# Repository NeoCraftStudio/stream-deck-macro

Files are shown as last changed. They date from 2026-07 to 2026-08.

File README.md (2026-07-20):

# Stream Deck Macro

DIY macro deck (Elgato Stream Deck style), built around an Arduino Pro Micro
(ATmega32U4): 4x4 button matrix with a secondary layer (2FX), 3 rotary
encoders for audio control, and individually addressable WS2812B LEDs per
key.

A companion Python app (PySide6) receives firmware events over serial and
executes the configured actions: keyboard shortcuts, OBS scene control, sound
playback, and real per-app mute.

## Status

In active development. Firmware phases (matrix, encoder, LEDs) verified on
hardware; app-side phases (serial reader, config, keyboard/audio/OBS
actions, 2FX logic) verified individually. Full roadmap below.

## Roadmap

```mermaid
flowchart TD
    S["Setup: Git + GitHub + Docs"]:::done --> P0["Phase 0: Hardware check"]:::done
    P0 --> P1["Phase 1: Firmware bring-up"]:::done
    P1 --> P2["Phase 2: Button matrix"]:::done
    P2 --> P3["Phase 3: Encoders"]:::done
    P3 --> P4["Phase 4: WS2812B LEDs"]:::done
    P4 --> P5["Phase 5: Merge + two-way protocol"]:::done
    P5 --> P6["Phase 6: App serial reader"]:::done
    P6 --> P7["Phase 7: Config format"]:::done
    P7 --> P8["Phase 8: Keyboard shortcuts"]:::done
    P8 --> P9["Phase 9: Audio playback"]:::done
    P9 --> P10["Phase 10: OBS control"]:::done
    P10 --> P11["Phase 11: Per-process mute"]:::done
    P11 --> P12["Phase 12: 2FX state machine"]:::done
    P12 --> P13["Phase 13: GUI (PySide6)"]:::done
    P13 --> P14["Phase 14: Full integration"]:::done
    P14 --> P15["Phase 15: Packaging .exe"]:::current
    P0 -.-> C["Case: 3D-printed enclosure"]:::todo
    C -.-> P14

    classDef done fill:#2ea043,stroke:#2ea043,color:#fff
    classDef current fill:#d29922,stroke:#d29922,color:#000
    classDef todo fill:#30363d,stroke:#8b949e,color:#c9d1d9
```

Full checklist with descriptions: [ROADMAP.md](ROADMAP.md)

## Learning project

This repository is also a learning exercise in Git, GitHub, and Python.

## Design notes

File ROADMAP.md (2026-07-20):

# Roadmap

Each phase is a prerequisite for the next one, unless marked as a parallel
track. Status is updated manually as the project progresses.

> **🟢 Resolved (2026-07-19): the Pro Micro's USB enumeration failure was a
> reset-timing issue (double-tap RST/GND needs to happen mid-upload, not
> before), not a hardware fault — same board recovered, no replacement
> needed. Details in `CLAUDE.md`.**

```mermaid
flowchart TD
    S["Setup: Git + GitHub + Docs"]:::done --> P0["Phase 0: Hardware check"]:::done
    P0 --> P1["Phase 1: Firmware bring-up"]:::done
    P1 --> P2["Phase 2: Button matrix"]:::done
    P2 --> P3["Phase 3: Encoders"]:::done
    P3 --> P4["Phase 4: WS2812B LEDs"]:::done
    P4 --> P5["Phase 5: Merge + two-way protocol"]:::done
    P5 --> P6["Phase 6: App serial reader"]:::done
    P6 --> P7["Phase 7: Config format"]:::done
    P7 --> P8["Phase 8: Keyboard shortcuts"]:::done
    P8 --> P9["Phase 9: Audio playback"]:::done
    P9 --> P10["Phase 10: OBS control"]:::done
    P10 --> P11["Phase 11: Per-process mute"]:::done
    P11 --> P12["Phase 12: 2FX state machine"]:::done
    P12 --> P13["Phase 13: GUI (PySide6)"]:::done
    P13 --> P14["Phase 14: Full integration"]:::done
    P14 --> P15["Phase 15: Packaging .exe"]:::current
    P0 -.-> C["Case: 3D-printed enclosure"]:::todo
    C -.-> P14

    classDef done fill:#2ea043,stroke:#2ea043,color:#fff
    classDef current fill:#d29922,stroke:#d29922,color:#000
    classDef todo fill:#30363d,stroke:#8b949e,color:#c9d1d9
```

🟢 done · 🟡 current · ⬛ not started

## Checklist

- [x] Setup — Git, GitHub repo, README, LICENSE, .gitignore, CLAUDE.md
- [x] Phase 0 — Hardware check (confirmed: Pro Micro 5V / 16MHz variant, no level shifter needed)
- [x] Phase 1 — Firmware bring-up (toolchain, blink, serial hello world)
- [x] Phase 2 — Firmware: button matrix scanning (all 16 positions confirmed)
- [x] Phase 3 — Firmware: rotary encoders (CW/CCW/PUSH logic verified on 1 of 3 encoders; other 2 are only repeats of the same wiring, to be confirmed when in hand)
- [x] Phase 4 — Firmware: WS2812B LEDs (chaining + color order confirmed on 9 spare bare LEDs; original 100+ LED reel is faulty, unresolved — see CLAUDE.md)
- [x] Phase 5 — Firmware: merge (matrix + encoder + LEDs, one sketch) done; **two-way protocol (PC→firmware LED commands) deliberately deferred** — revisit before Phase 14
- [x] Phase 6 — App: serial reader (pyserial), confirmed reading BTN/ENC events live
- [x] Phase 7 — App: config file format (JSON schema designed, `config.json` sample + loader confirmed working)
- [x] Phase 8 — App: keyboard shortcut execution (`pyautogui`, confirmed via config-driven `ctrl+c` test)
- [x] Phase 9 — App: audio playback (`sounddevice`, confirmed routing through VB-Cable to a specific device)
- [x] Phase 10 — App: OBS control (`obsws-python`, confirmed scene switch)
- [x] Phase 11 — App: real per-process mute (`pycaw`, mute + unmute both confirmed on `opera.exe`)
- [x] Phase 12 — App: 2FX layer state machine (arm/cancel/timeout/layer-2-fire all confirmed against real hardware)
- [x] Phase 13 — App: GUI (PySide6) — grid, per-key config popup (incl. recorded-macro type), 2FX timeout settings, and per-encoder config (system vs. per-app via file picker) all confirmed saving to config.json
- [x] Phase 14 — Full integration: firmware two-way command (`LED:SOLID:r,g,b`) confirmed, app listens to serial live via a `QTimer` (non-blocking, GUI stays responsive) and executes real actions (keyboard/macro, sound, OBS scene) through the 2FX logic. Follow-up polish (not blocking): app doesn't yet send LED feedback on 2FX arm/disarm, encoder events not yet wired to volume/mute.
- [ ] Phase 15 — Packaging (PyInstaller .exe) **← current**
- [ ] Case — 3D-printed enclosure (parallel track, not blocking)

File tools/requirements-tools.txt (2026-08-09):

# Build-time-only tools — NOT runtime dependencies of app.py.
# Install into .venv only when regenerating the icon or the manual PDF:
#   pip install -r tools/requirements-tools.txt
pillow
markdown
pymupdf
pyinstaller

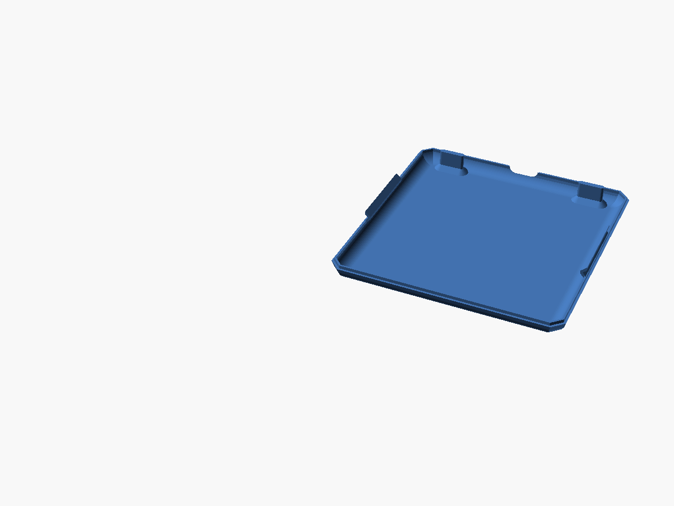
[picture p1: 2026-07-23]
case/renders/ocreeb_bottom_original.png

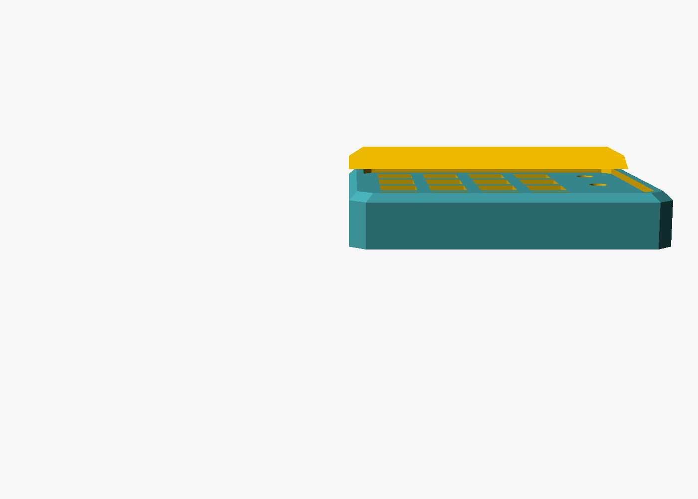
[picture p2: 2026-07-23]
case/renders/case_v5_riser_side.png

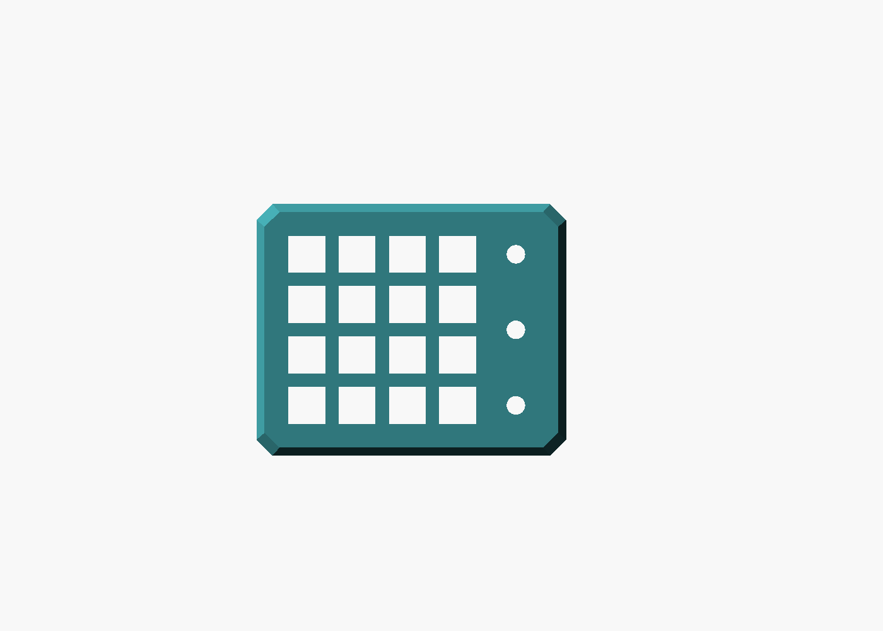
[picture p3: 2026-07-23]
case/renders/case_v4_top_view.png

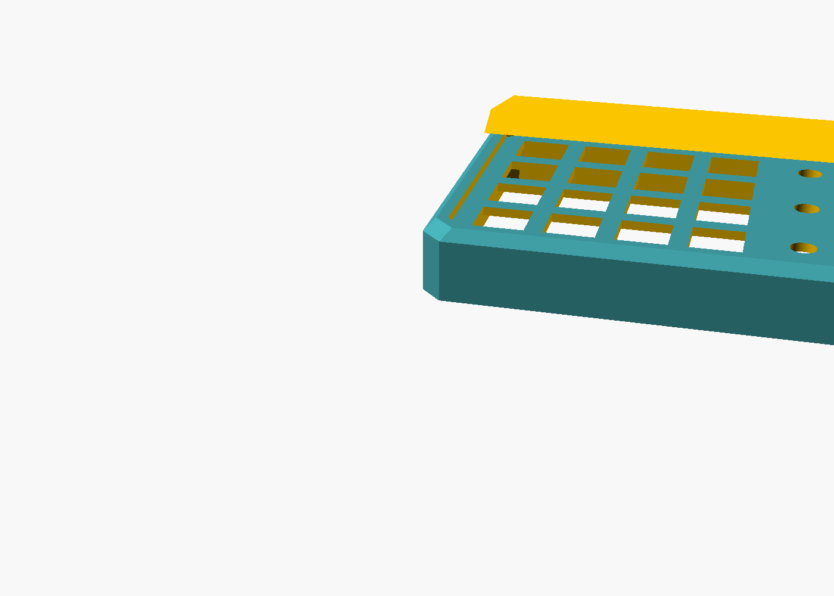
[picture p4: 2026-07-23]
case/renders/case_v5_check.png

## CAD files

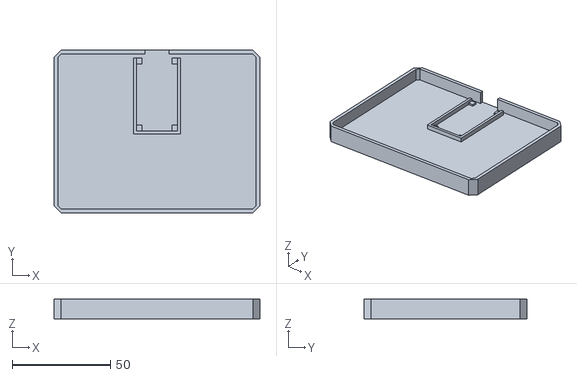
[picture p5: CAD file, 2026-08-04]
case/case_bottom.stl
104.7 x 82.7 x 10.0

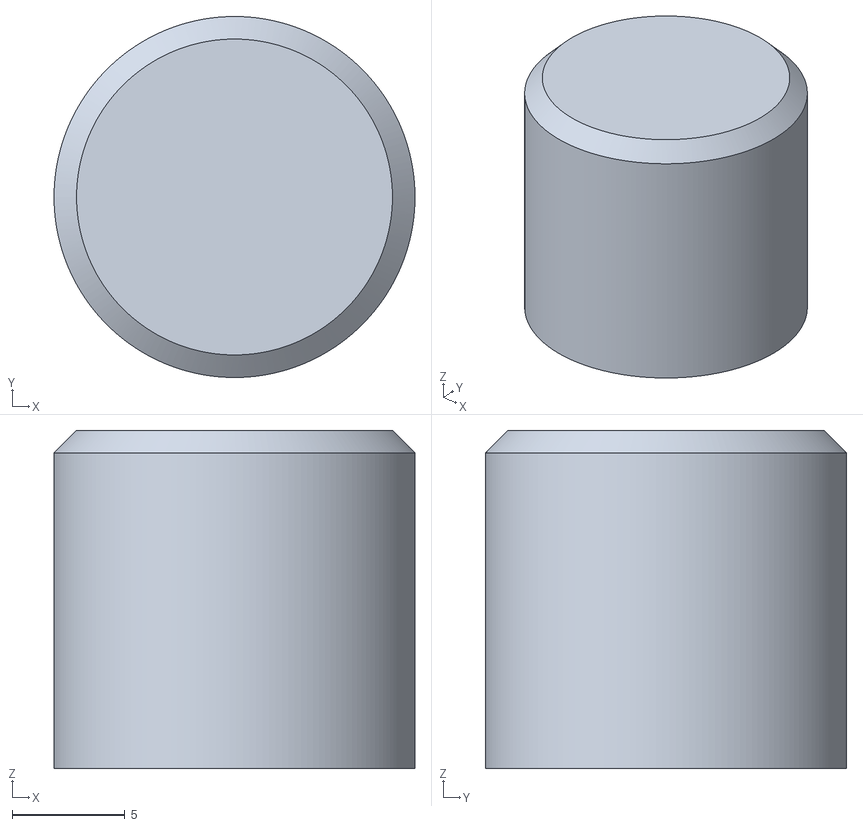
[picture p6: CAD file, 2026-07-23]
case/reference/Knob.stl
16.0 x 16.0 x 15.0

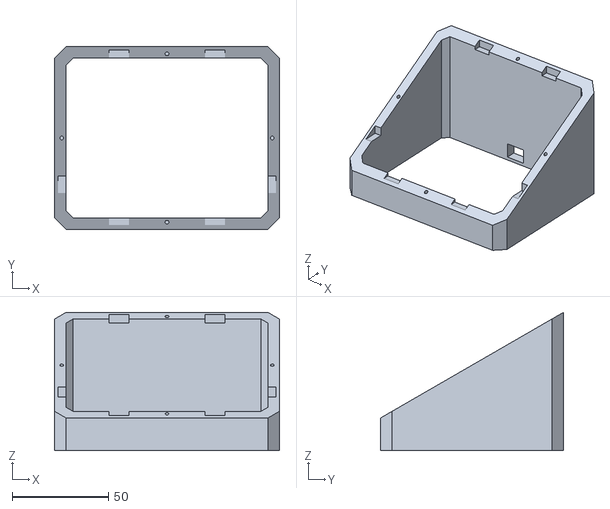
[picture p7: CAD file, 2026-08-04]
case/case_mount.stl
117.2 x 95.2 x 71.9

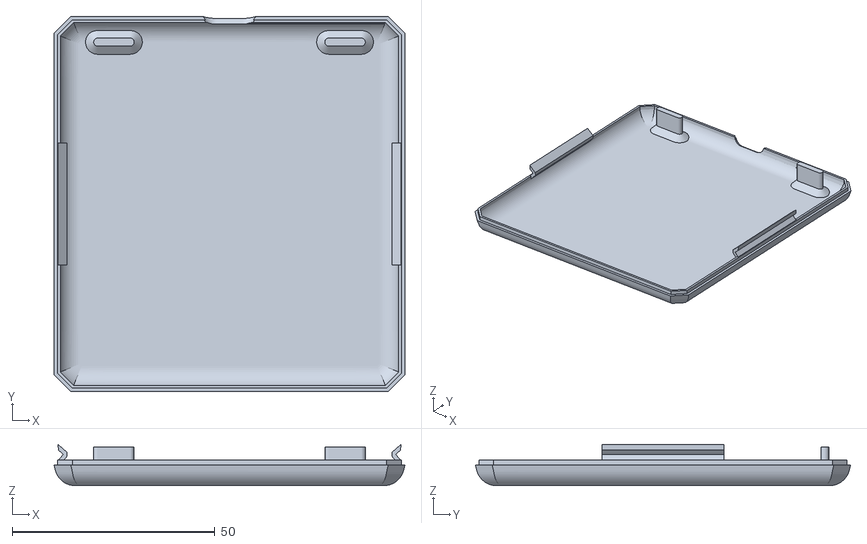
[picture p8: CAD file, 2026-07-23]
case/reference/Case_Bottom.stl
86.6 x 92.5 x 10.2

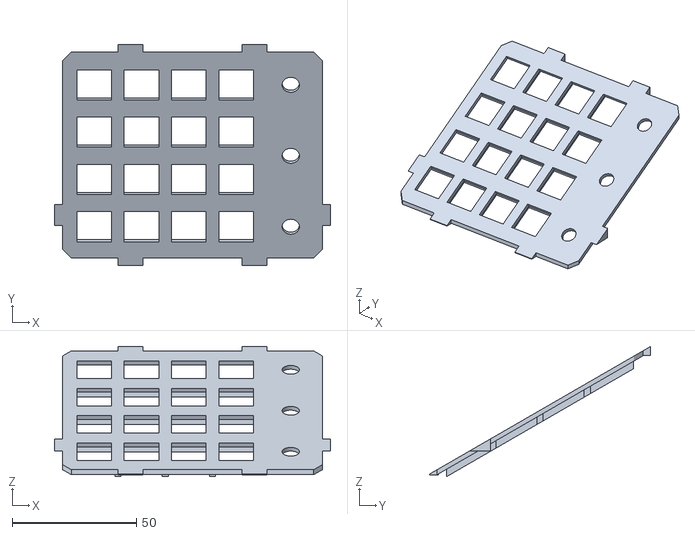
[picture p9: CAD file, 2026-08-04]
case/case_deck.stl
111.2 x 89.2 x 52.4

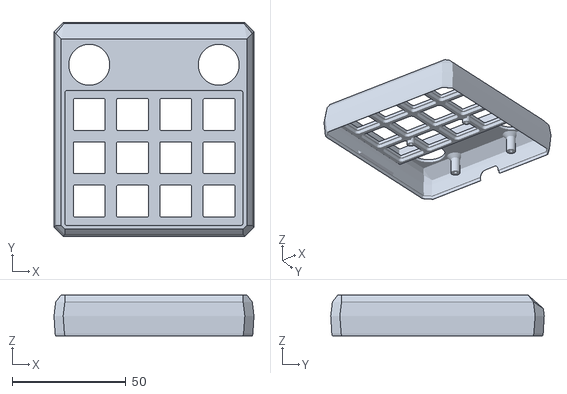
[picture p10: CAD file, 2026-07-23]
case/reference/Case_Top.stl
88.0 x 94.0 x 18.0

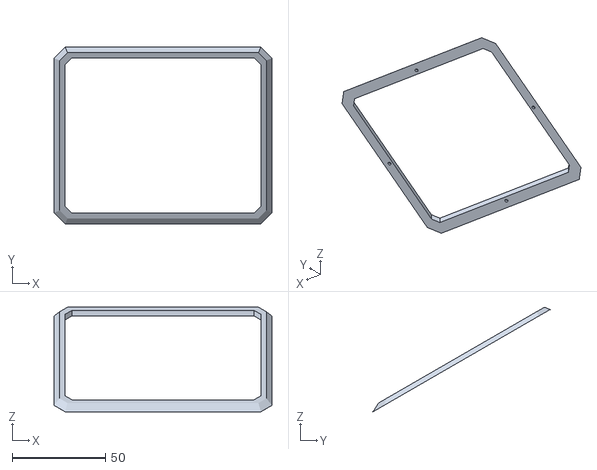
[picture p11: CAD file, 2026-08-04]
case/case_crest.stl
117.2 x 95.2 x 56.2

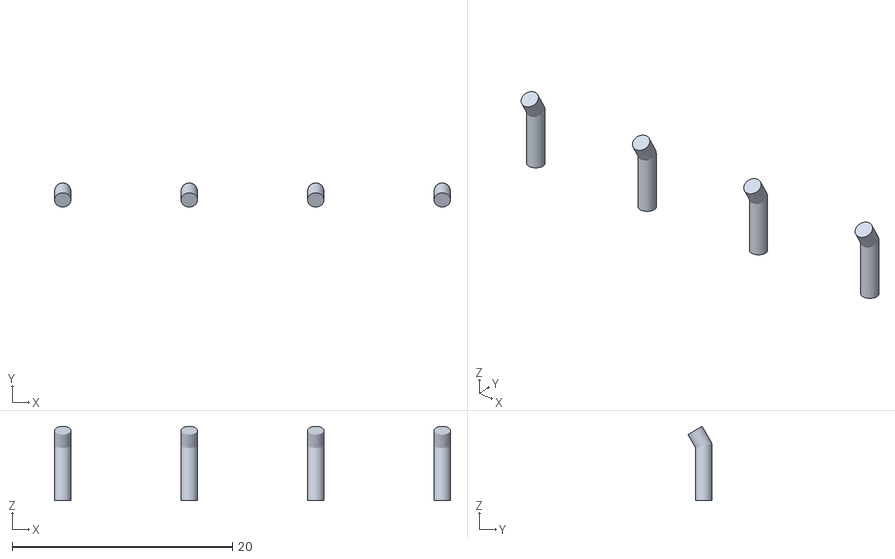
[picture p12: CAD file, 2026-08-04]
case/case_pins.stl
36.0 x 2.20 x 6.76

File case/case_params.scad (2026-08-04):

// Stream Deck Macro — shared case dimensions (included by top/bottom/assembly)

// ---- Our target layout ----
switch_hole   = 14;
switch_pitch  = 19.05;
grid_cols     = 4;
grid_rows     = 4;
grid_span     = (grid_cols - 1) * switch_pitch + switch_hole; // 71.15

encoder_d     = 7;       // CONFIRMED two ways: caliper-measured on the actual purchased part,
                          // and matches the encoder's own spec — Keszoox's EC11 datasheet states
                          // "Panel Mount — M7 thread fits standard 7mm panel holes with included
                          // nut" for this exact family (EC11, 15mm shaft, half/D-shaft — matches
                          // the purchased "G 15mm Half handle" spec). No longer a placeholder.
encoder_count = 3;
encoder_gap   = 15;

margin = 12;

// ---- Shell style ----
corner_chamfer = 6;    // diagonal cut on each of the 4 corners
rim_height     = 20;   // total wall height (top to bottom), 2cm per feedback
bevel_height   = 3;    // top tapered collar height
bevel_inset    = 3;    // how far the top face is inset from the outer wall
border         = 6;    // rim wall thickness (outer edge to inner hollow)
deck_recess    = 2.5;  // how far below the rim top the switch deck sits
deck_thickness = 2.5;  // thickness of the switch deck floor

// switch_hole (14mm) and switch_pitch (19.05mm) are the universal Cherry
// MX-compatible plate-mount standard — every mechanical switch
// manufacturer uses this same spacing, Outemu (the purchased switch,
// "Dustproof Brown") included. Not brand-specific, so there's nothing to
// confirm against the specific part the way encoder_d needed — this was
// already correct.

plate_w = margin*2 + grid_span + encoder_gap + encoder_d;
plate_d = margin*2 + grid_span;

// ---- Arduino Pro Micro mount (off-the-shelf part) ----
// CONFIRMED (AliExpress order, seller A+A+A Store): "MICRO/MINI/TYPE-C USB
// Pro Micro para arduino ATmega32U4", ordered as TYPE-C USB 5V/16MHz — NOT
// Micro-USB, correcting an earlier assumption this file was built around.
// Board size still web-sourced, not caliper-measured: multiple listings
// (Probots, Envistia Mall, Makers Electronics) cite ~33x18mm for this
// family; Keebio notes the USB-C variant specifically runs ~3mm longer
// than the Micro-USB version (~36mm) because of the connector footprint.
// arduino_l=38 already covers that with ~2mm to spare. Confirm with
// calipers before printing final — same convention as encoder_d.
//
// USB-C connector: standard panel-mount cutout per connector datasheets is
// 12mm x 8.4mm (the bare plug shell is ~8.4mm wide x 2.6-2.9mm tall, but
// the cable's outer sleeve needs the fuller cutout to actually pass
// through). usb_cutout_w/h below (12x9) already satisfy that with a
// little extra margin on height — no change needed now that the
// connector type is confirmed, this is just the correct citation for why
// those numbers work, replacing the old Micro-USB-based reasoning.
arduino_l          = 37;   // pocket length (Y) — tightened from a generic 38mm margin. Better
                            // data now: base Pro Micro is ~33mm, and Keebio (who sells the exact
                            // USB-C variant) states it specifically runs ~3mm longer than the
                            // Micro-USB version because of the connector footprint = ~36mm for
                            // this board. 37mm leaves 1mm clearance, tighter than before because
                            // this number is better-reasoned now, not because the underlying
                            // uncertainty (calipers not yet done) has changed.
arduino_w          = 21;   // pocket width (X) — board's ~18-18.4mm wide edge + margin. Width
                            // doesn't vary between Micro-USB/USB-C variants (only length does,
                            // from the connector), so no equivalent tightening applies here.
arduino_wall_t     = 1.5;  // retaining wall thickness (bottom tray)
arduino_wall_h     = 2.5;  // retaining wall height — keeps the board from sliding sideways
arduino_standoff_h = 1;    // corner standoff height — lifts the board off the floor slightly,
                            // clearing any solder blobs on the underside

usb_cutout_w  = 12;  // wall cutout width — matches the standard USB-C panel cutout width
usb_cutout_h  = 9;   // wall cutout height — standard USB-C panel cutout is 8.4mm; 9mm keeps
                      // a small margin above that
usb_cutout_z0 = 2;   // wall cutout bottom, world Z — still an ESTIMATE (~5.5mm port center
                      // above the tray floor), not measured against the actual board's port
                      // height. This is unrelated to the Micro-USB/USB-C question and still
                      // needs a test-fit or caliper check before printing final.

// Board centered in X, pushed to the BACK (max Y) of the case, USB port
// facing the back wall so the cable exits there — position shared between
// case_v4_bottom.scad (the pocket) and case_v4_top.scad (the wall cutout)
// so they're guaranteed to align, rather than two separately-guessed numbers.
arduino_x_center = plate_w / 2;
arduino_y_back   = plate_d - border - 4.25; // The tray's own inner cavity back boundary sits at
                            // plate_d - border - fit_clearance(0.25) - wall_thickness(2) = 86.9,
                            // not plate_d - border(89.15) — those extra two values belong to
                            // case_v4_bottom.scad specifically. Using -4.25 here (2mm safety
                            // margin past that real boundary) keeps the pocket safely inside the
                            // tray's actual cavity instead of overlapping its own back wall.

module chamfered_rect(w, d, c) {
    polygon(points = [
        [c, 0], [w - c, 0],
        [w, c], [w, d - c],
        [w - c, d], [c, d],
        [0, d - c], [0, c]
    ]);
}

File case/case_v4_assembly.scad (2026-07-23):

// Fit-check only — both pieces as plain solid geometry.

include <case_params.scad>
use <case_v4_top.scad>
use <case_v4_bottom.scad>

case_top();
case_bottom();

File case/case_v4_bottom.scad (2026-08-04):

// Stream Deck Macro — bottom plate v4 (tray with sliding wall)
// Slides up into the top piece's inner cavity from below. The tray's outer
// wall matches the top's inner hollow, minus a small per-side clearance so
// it can actually slide in once printed.

include <case_params.scad>

fit_clearance    = 0.25; // per-side gap for a sliding fit
floor_thickness  = 3;    // tray floor thickness
wall_thickness   = 2;    // tray's own perimeter wall thickness
wall_height      = 10;   // how tall the tray wall is (slides into the top's cavity)

bottom_w = (plate_w - 2*border) - 2*fit_clearance;
bottom_d = (plate_d - 2*border) - 2*fit_clearance;
bottom_chamfer = corner_chamfer * 0.6;

module arduino_mount() {
    // 3-sided retaining wall — left, right, and the far (low-Y) side —
    // left OPEN on the back (high-Y) side facing the USB cutout, so
    // there's nothing blocking cable clearance or sliding the board in
    // from that direction. Corner standoffs lift the board slightly off
    // the floor.
    z0 = floor_thickness;
    x0 = arduino_x_center - arduino_w/2;
    y0 = arduino_y_back - arduino_l;
    translate([x0 - arduino_wall_t, y0, z0])
        cube([arduino_wall_t, arduino_l, arduino_wall_h]);
    translate([x0 + arduino_w, y0, z0])
        cube([arduino_wall_t, arduino_l, arduino_wall_h]);
    translate([x0 - arduino_wall_t, y0 - arduino_wall_t, z0])
        cube([arduino_w + 2*arduino_wall_t, arduino_wall_t, arduino_wall_h]);
    standoff_size = 3;
    for (dx = [0, arduino_w - standoff_size])
        for (dy = [0, arduino_l - standoff_size])
            translate([x0 + dx, y0 + dy, z0])
                cube([standoff_size, standoff_size, arduino_standoff_h]);
}

module case_bottom() {
    translate([border + fit_clearance, border + fit_clearance, 0])
        difference() {
            linear_extrude(height = wall_height)
                chamfered_rect(bottom_w, bottom_d, bottom_chamfer);
            translate([wall_thickness, wall_thickness, floor_thickness])
                linear_extrude(height = wall_height)
                    chamfered_rect(bottom_w - 2*wall_thickness,
                                   bottom_d - 2*wall_thickness,
                                   max(bottom_chamfer - wall_thickness, 0.1));
            // USB cable notch through the TRAY'S OWN back wall — without
            // this, the wall added a few lines above (wall_thickness
            // thick) sits directly between the Arduino pocket and the
            // matching cutout in the mount's back wall, blocking the
            // cable path entirely. Reported directly: "the hole for the
            // cable is blocked for the back wall of the bottom."
            // bottom_w/2 in this LOCAL frame is exactly arduino_x_center
            // in world coordinates (border+fit_clearance cancels out),
            // so this lines up with the mount's cutout without needing
            // to duplicate that math.
            translate([bottom_w/2 - usb_cutout_w/2, bottom_d - wall_thickness - 1, floor_thickness])
                cube([usb_cutout_w, wall_thickness + 2, wall_height - floor_thickness + 1]);
        }
    arduino_mount();
}

case_bottom();

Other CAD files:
case/case_v4_top.scad
case/case_v2_top.scad
case/case_v3_top.scad
case/debug_assembly.scad
case/plate_v1.scad
case/view_ocreeb_bottom.scad
case/view_ocreeb_top.scad

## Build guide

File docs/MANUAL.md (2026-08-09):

# NeoCraft Macro Desk — User Manual

A custom macro pad: a 4×4 button grid plus 3 rotary encoders, paired with a
Windows desktop app that decides what each button and encoder does.

---

## Part 1 — What it does

### The hardware
- **16 buttons** arranged in a 4×4 grid. 15 of them (`BTN0`–`BTN14`) run
  actions you assign. The 16th, **`2FX`**, is not an action button — it's a
  layer switch (see below).
- **3 rotary encoders** (`ENC1`–`ENC3`). Turning one adjusts a volume; clicking
  it in mutes/unmutes. *Currently only ENC1 is wired up in the firmware —
  ENC2 and ENC3 are physically present but not active yet.*
- **Addressable LEDs**, one per key, showing an animated color pattern while
  everything's connected, or **solid red** if the app isn't running/connected
  — a built-in reminder to start the app.

### The app
A small program that lives in your system tray. It talks to the pad over
USB and lets you assign an action to every button, and a volume target to
every encoder. Each button can do one of these:

| Action type | What it does |
|---|---|
| **Keyboard** | Sends a key combo (e.g. `ctrl+c`) to whatever app is focused |
| **Macro** | Same as Keyboard, but you record the combo by pressing it live instead of typing it |
| **OBS Scene** | Switches OBS Studio to a specific scene (requires OBS running with its WebSocket server on) |
| **Sound** | Plays an audio file (WAV, MP3, OGG, FLAC, AIFF) — with volume and trim controls |
| **Empty** | Does nothing (the button's default state) |

Each encoder can control either your **system's overall volume**, or the
volume of **one specific application** (even multi-window apps like a
browser) — your choice, set per encoder.

### The "2FX" second layer
Every button can hold **two different actions** — a normal one (Layer 1) and
a second one (Layer 2) that only fires when you deliberately arm it:

1. Tap **`2FX`** — the border flashes red, Layer 2 is now armed.
2. Tap any other button — it runs *that button's Layer 2 action*, then the
   pad automatically drops back to Layer 1.
3. If you don't press anything, Layer 2 auto-cancels after a timeout
   (10 seconds by default, adjustable up to 60s).
4. Tapping **`2FX`** again while armed cancels it manually, with no action
   run.

This is how one 16-key pad gives you effectively 30 assignable actions.

### Background operation
Closing the app window (the **X** button) doesn't quit it — it minimizes to
the system tray and keeps running, so your button/encoder mappings stay
active. Use the tray icon's **Quit** option to fully exit.

### Language
The app is available in **English** and **Português**, switchable at any
time from Settings (see [Changing the app language](#changing-the-app-language)).
Defaults to Português. *Note: the screenshots in this manual were captured
before this feature existed, so a few labels shown (dialog titles, button
text) are in whichever language they defaulted to at the time — the dialog
layout and flow are identical, only the wording changes per language now.*

---

## Part 2 — Installation

1. Download `NeoCraft-Macro-Desk-Setup.exe`.
2. Double-click it. **No administrator prompt will appear** — this installs
   just for your Windows account, not system-wide.
3. Optionally check **"Create a desktop shortcut"** in the wizard.
4. Click through to finish. The installer creates a Start Menu entry
   (**NeoCraft Macro Desk**) and an uninstaller.
5. Plug in the macro pad via USB.
6. Launch the app (Start Menu, or the desktop shortcut if you created one).

The app connects automatically — no setup dialog, no drivers to install
separately (Windows' built-in USB-serial driver handles the Pro Micro).
It finds the pad by its USB identity, not a fixed COM port number, so it
connects correctly no matter which COM port Windows assigns it (which can
change if you plug it into a different USB port).

**If the LEDs stay solid red after launching the app:** the app isn't
seeing the pad at all — check the USB cable/connection, and confirm it
shows up in Windows Device Manager under Ports (COM & LPT).

**To uninstall:** Start Menu → NeoCraft Macro Desk → "Uninstall NeoCraft
Macro Desk," or Windows Settings → Apps. Your saved button/encoder
configuration is kept (in case you reinstall later) — see
[Where your settings are saved](#where-your-settings-are-saved) if you want
to remove it manually too.

---

## Part 3 — How to use each function

### The main window

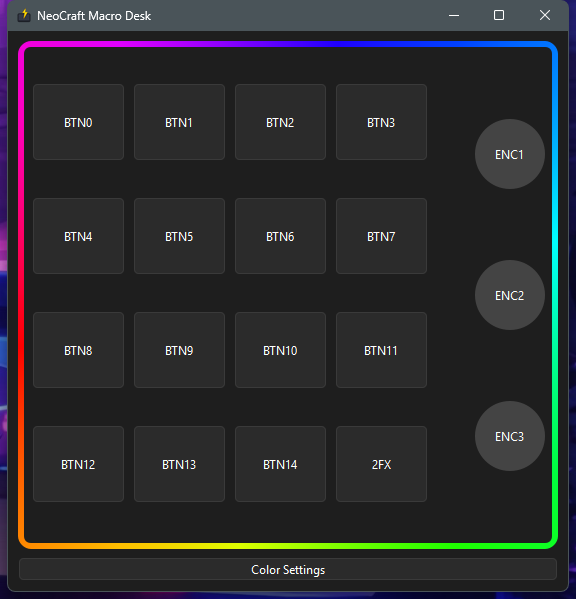
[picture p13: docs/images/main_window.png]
Main window


*Note: this screenshot predates a small layout change — the single bottom
button is now three side by side: **Color Settings**, **Settings**, and
**Help** (see below).*

A 4×4 grid of buttons plus the 3 encoders on the right. The animated border
shows the pad's current LED pattern live. Click **any button** to configure
it. Below the grid, three buttons:
- **Color Settings** — change the LED pattern (see
  [Changing the LED pattern](#changing-the-led-pattern)).
- **Settings** — 2FX timeout and app language (see
  [Changing the app language](#changing-the-app-language)).
- **Help** — app version and links to this manual and the GitHub repo (see
  [Help](#help)).

### Assigning a keyboard shortcut or macro to a button

1. Click the button you want to configure (e.g. `BTN0`).
2. Choose the **Layer** (Layer 1 = normal, Layer 2 (2FX) = second function).
3. Set **Action type** to **Keyboard** or **Macro**.
   - **Keyboard**: type the combo directly, e.g. `ctrl+c`.
   - **Macro**: click into the field and press the actual key combo on your
     keyboard — it's captured live.
4. Click **OK** to save.

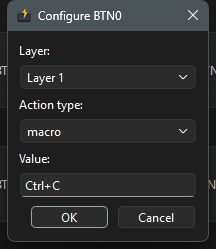
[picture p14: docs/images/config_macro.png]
Macro configuration


### Assigning a sound to a button

1. Click the button, set **Action type** to **Sound**.
2. Click **Browse...** and pick an audio file (WAV, MP3, OGG, FLAC, or AIFF).
3. Adjust **Volume** with the slider (0–100%).
4. Drag the two handles under **Trim** to play only part of the clip — the
   label below shows the selected start/end time and the clip's total
   length.
5. Use **▶ Play preview** / **■ Stop** to check it sounds right before
   saving.
6. Click **OK**.

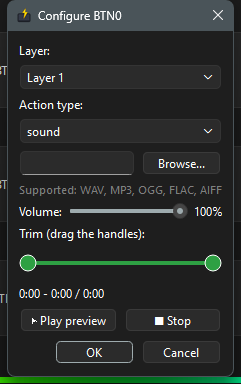
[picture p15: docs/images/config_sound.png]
Sound configuration


### Assigning an OBS scene switch

1. Click the button, set **Action type** to **OBS Scene**.
2. Type the exact scene name as it appears in OBS.
3. Click **OK**.

This requires OBS Studio running with its WebSocket server enabled
(OBS 28+ has this built in — Tools → WebSocket Server Settings).

### Clearing a button

Set its **Action type** to **Empty** and click **OK**.

### Using the 2FX second layer

Tap the **`2FX`** key on the pad (bottom-right of the grid). The app border
flashes red while armed. The next button you press runs its **Layer 2**
action instead of Layer 1, then the pad returns to normal automatically. Tap
`2FX` again before pressing anything else to cancel without running an
action.

To change how long Layer 2 stays armed before auto-canceling, click the
**Settings** button below the grid:

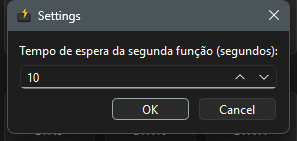
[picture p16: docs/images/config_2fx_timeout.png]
Settings dialog


### Changing the app language

Open the same **Settings** dialog and use the **Language** / **Idioma**
dropdown at the bottom — pick **English** or **Português** and click **OK**.
The change applies immediately: any dialog you open next (button config,
encoder config, color settings) shows the new language right away, no
restart needed. The **Color Settings**/**Settings**/**Help** buttons and the
tray menu's Open/Quit labels update immediately too.

### Help

Click the **Help** button below the grid for the app's version number and
two links — one to this manual on GitHub, one to the project's GitHub repo.
Both open in your default browser.

### Configuring an encoder

1. Click an encoder (`ENC1`, `ENC2`, or `ENC3`) in the app window.
2. Choose the mode:
   - **System Volume** (**Volume Geral** in Português) — controls your
     system's overall Windows volume.
   - **Application** (**Aplicativo**) — controls one specific application's
     volume independently (click **Select...** and pick its `.exe`). This
     works correctly even for apps that run as many processes at once,
     like Chromium-based browsers.
3. Click **OK**.

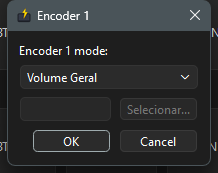
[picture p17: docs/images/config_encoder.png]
Encoder configuration


Once configured: **turn** the encoder to adjust volume up/down, **click** it
(push down) to mute/unmute.

### Changing the LED pattern

Click **Color Settings** at the bottom of the main window.

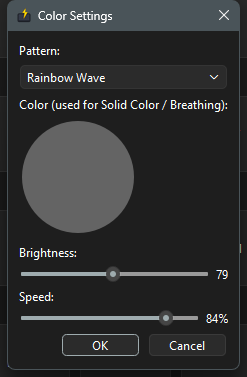
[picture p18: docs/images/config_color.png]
Color settings


- **Pattern**: Solid Color, Breathing, Rainbow Wave, or Color Cycle.
- **Color**: pick a color on the wheel — only used by Solid Color and
  Breathing (grayed out otherwise, since Rainbow Wave and Color Cycle
  generate their own colors).
- **Brightness** / **Speed**: sliders, applied immediately and saved with
  the rest of your settings.

### The system tray icon

Tray menu

Right-click (or on some systems, left-click) the tray icon for:
- **Open** — bring the main window back.
- **Quit** — fully close the app (button/encoder mappings stop working
  until you reopen it, and the pad's LEDs go solid red).

### Where your settings are saved

Your button mappings, encoder targets, and color settings are stored in:

```
%APPDATA%\NeoCraft Macro Desk\config.json
```

This file persists across app updates and reinstalls. Deleting it resets
everything to defaults the next time the app starts.

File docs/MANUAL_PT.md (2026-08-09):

# NeoCraft Macro Desk — Manual do Usuário

Um macro pad personalizado: uma grade de 16 botões (4×4) mais 3 encoders
rotativos, junto com um aplicativo de desktop para Windows que decide o que
cada botão e encoder faz.

---

## Parte 1 — O que ele faz

### O hardware
- **16 botões** organizados em uma grade 4×4. 15 deles (`BTN0`–`BTN14`)
  executam ações que você define. O 16º, **`2FX`**, não é um botão de ação —
  é uma tecla de troca de camada (veja abaixo).
- **3 encoders rotativos** (`ENC1`–`ENC3`). Girar ajusta um volume; clicar
  (apertar) muta/desmuta. *No momento, apenas o ENC1 está ativo no
  firmware — ENC2 e ENC3 estão fisicamente presentes, mas ainda não
  funcionam.*
- **LEDs endereçáveis**, um por tecla, mostrando um padrão de cor animado
  enquanto tudo está conectado, ou **vermelho sólido** se o aplicativo não
  estiver rodando/conectado — um lembrete visual embutido para abrir o app.

### O aplicativo
Um programinha que fica na bandeja do sistema (system tray). Ele conversa
com o pad via USB e permite atribuir uma ação a cada botão, e um alvo de
volume a cada encoder. Cada botão pode fazer uma destas ações:

| Tipo de ação | O que faz |
|---|---|
| **Teclado** | Envia uma combinação de teclas (ex.: `ctrl+c`) para o app que estiver em foco |
| **Macro** | Igual ao Teclado, mas você grava a combinação apertando-a de verdade, em vez de digitar |
| **Cena OBS** | Troca a cena do OBS Studio para uma cena específica (requer o OBS rodando com o servidor WebSocket ligado) |
| **Som** | Toca um arquivo de áudio (WAV, MP3, OGG, FLAC, AIFF) — com controles de volume e corte |
| **Vazio** | Não faz nada (estado padrão do botão) |

Cada encoder pode controlar o **volume geral do sistema**, ou o volume de
**um aplicativo específico** (mesmo apps com várias janelas, como um
navegador) — você escolhe, por encoder.

### A segunda camada "2FX"
Todo botão pode ter **duas ações diferentes** — uma normal (Camada 1) e uma
segunda (Camada 2) que só dispara quando você arma deliberadamente:

1. Toque em **`2FX`** — a borda do app pisca vermelho, a Camada 2 fica
   armada.
2. Toque em qualquer outro botão — ele executa *a ação da Camada 2 daquele
   botão*, e o pad volta automaticamente para a Camada 1.
3. Se você não apertar nada, a Camada 2 se desarma sozinha depois de um
   tempo (10 segundos por padrão, ajustável até 60s).
4. Tocar em **`2FX`** de novo enquanto está armado cancela manualmente, sem
   executar nenhuma ação.

É assim que um pad de 16 teclas te dá, na prática, 30 ações configuráveis.

### Funcionamento em segundo plano
Fechar a janela do app (o botão **X**) não encerra o programa — ele
minimiza para a bandeja do sistema e continua rodando, então seus mapeamentos
de botões/encoders continuam ativos. Use a opção **Sair** no menu da bandeja
para encerrar de verdade.

### Idioma
O aplicativo está disponível em **Português** e **English**, trocável a
qualquer momento em Configurações (veja
[Trocando o idioma do aplicativo](#trocando-o-idioma-do-aplicativo)).
O padrão é Português. *Nota: as capturas de tela deste manual foram feitas
antes desse recurso existir, então alguns rótulos mostrados (títulos de
janela, texto de botão) estão no idioma que era padrão na época — o layout
e o fluxo das janelas são idênticos, só o texto muda conforme o idioma
agora.*

---

## Parte 2 — Instalação

1. Baixe o `NeoCraft-Macro-Desk-Setup.exe`.
2. Dê duplo clique nele. **Nenhuma solicitação de administrador vai
   aparecer** — a instalação é só para a sua conta do Windows, não para o
   sistema todo.
3. Opcionalmente marque **"Create a desktop shortcut"** no assistente.
4. Avance até o fim. O instalador cria uma entrada no Menu Iniciar
   (**NeoCraft Macro Desk**) e um desinstalador.
5. Conecte o macro pad via USB.
6. Abra o aplicativo (Menu Iniciar, ou o atalho na área de trabalho, se
   você criou um).

O aplicativo conecta automaticamente — sem tela de configuração, sem
drivers para instalar separadamente (o driver USB-serial embutido do
Windows já cuida do Pro Micro). Ele encontra o pad pela identidade USB
dele, não por um número fixo de porta COM, então conecta corretamente
não importa em qual porta COM o Windows o coloque (o que pode mudar se
você plugar em uma porta USB diferente).

**Se os LEDs ficarem vermelho sólido depois de abrir o app:** o aplicativo
não está enxergando o pad de jeito nenhum — confira o cabo/conexão USB, e
confirme que ele aparece no Gerenciador de Dispositivos do Windows, em
Portas (COM & LPT).

**Para desinstalar:** Menu Iniciar → NeoCraft Macro Desk → "Uninstall
NeoCraft Macro Desk", ou Configurações do Windows → Aplicativos. Sua
configuração salva de botões/encoders é mantida (caso você reinstale
depois) — veja
[Onde suas configurações ficam salvas](#onde-suas-configurações-ficam-salvas)
se quiser removê-la manualmente também.

---

## Parte 3 — Como usar cada função

### A janela principal

Janela principal

*Nota: esta captura de tela é de antes de uma pequena mudança de layout —
o único botão embaixo agora são três, lado a lado: **Configurações de
Cor**, **Configurações** e **Ajuda** (veja abaixo).*

Uma grade 4×4 de botões, mais os 3 encoders à direita. A borda animada
mostra o padrão de LED atual do pad, ao vivo. Clique em **qualquer botão**
para configurá-lo. Abaixo da grade, três botões:
- **Configurações de Cor** — muda o padrão de LED (veja
  [Mudando o padrão de LED](#mudando-o-padrão-de-led)).
- **Configurações** — tempo da 2FX e idioma do app (veja
  [Trocando o idioma do aplicativo](#trocando-o-idioma-do-aplicativo)).
- **Ajuda** — versão do app e links para este manual e para o repositório
  no GitHub (veja [Ajuda](#ajuda)).

### Atribuindo um atalho de teclado ou macro a um botão

1. Clique no botão que quer configurar (ex.: `BTN0`).
2. Escolha a **Camada** (Camada 1 = normal, Camada 2 (2FX) = segunda
   função).
3. Defina o **Tipo de ação** como **Teclado** ou **Macro**.
   - **Teclado**: digite a combinação diretamente, ex.: `ctrl+c`.
   - **Macro**: clique no campo e aperte a combinação de verdade no seu
     teclado — ela é capturada ao vivo.
4. Clique em **OK** para salvar.

Configuração de macro

### Atribuindo um som a um botão

1. Clique no botão, defina o **Tipo de ação** como **Som**.
2. Clique em **Procurar...** e escolha um arquivo de áudio (WAV, MP3, OGG,
   FLAC ou AIFF).
3. Ajuste o **Volume** com o controle deslizante (0–100%).
4. Arraste as duas alças em **Corte** para tocar só parte do clipe — o
   texto abaixo mostra o início/fim selecionado e a duração total.
5. Use **▶ Testar som** / **■ Parar** para conferir se está do jeito certo
   antes de salvar.
6. Clique em **OK**.

Configuração de som

### Atribuindo uma troca de cena do OBS

1. Clique no botão, defina o **Tipo de ação** como **Cena OBS**.
2. Digite o nome exato da cena como aparece no OBS.
3. Clique em **OK**.

Isso requer o OBS Studio rodando com o servidor WebSocket habilitado (o
OBS 28+ já vem com isso — Tools → WebSocket Server Settings).

### Limpando um botão

Defina o **Tipo de ação** como **Vazio** e clique em **OK**.

### Usando a segunda camada 2FX

Toque na tecla **`2FX`** do pad (canto inferior direito da grade). A borda
do app pisca vermelho enquanto está armada. O próximo botão que você
apertar executa sua ação da **Camada 2** em vez da Camada 1, e o pad volta
ao normal automaticamente. Toque em `2FX` de novo antes de apertar outra
coisa para cancelar sem executar nenhuma ação.

Para mudar quanto tempo a Camada 2 fica armada antes de desarmar sozinha,
clique no botão **Configurações** abaixo da grade:

Janela de Configurações

### Trocando o idioma do aplicativo

Abra a mesma janela de **Configurações** e use o menu **Idioma** /
**Language** na parte de baixo — escolha **Português** ou **English** e
clique em **OK**. A mudança é aplicada na hora: qualquer janela que você
abrir em seguida (configurar botão, configurar encoder, configurações de
cor) já aparece no novo idioma, sem precisar reiniciar. Os botões
**Configurações de Cor**/**Configurações**/**Ajuda** e os textos **Abrir**/
**Sair** do menu da bandeja também atualizam na hora.

### Ajuda

Clique no botão **Ajuda** abaixo da grade para ver o número da versão do
app e dois links — um para este manual no GitHub, outro para o repositório
do projeto. Os dois abrem no seu navegador padrão.

### Configurando um encoder

1. Clique em um encoder (`ENC1`, `ENC2` ou `ENC3`) na janela do app.
2. Escolha o modo:
   - **Volume Geral** (**System Volume** em inglês) — controla o volume
     geral do Windows.
   - **Aplicativo** (**Application**) — controla o volume de um app
     específico, independentemente (clique em **Selecionar...** e escolha
     o `.exe`). Funciona corretamente até com apps que rodam como vários
     processos ao mesmo tempo, como navegadores baseados em Chromium.
3. Clique em **OK**.

Configuração de encoder

Depois de configurado: **gire** o encoder para ajustar o volume,
**clique** nele (aperte para baixo) para mutar/desmutar.

### Mudando o padrão de LED

Clique em **Configurações de Cor** na parte de baixo da janela principal.

Configurações de cor

- **Padrão**: Cor Sólida, Respiração, Onda Arco-íris ou Ciclo de Cor.
- **Cor**: escolha uma cor na roda — usada apenas por Cor Sólida e
  Respiração (fica desabilitada nos outros modos, já que Onda Arco-íris e
  Ciclo de Cor geram suas próprias cores).
- **Brilho** / **Velocidade**: controles deslizantes, aplicados na hora e
  salvos junto com o resto das suas configurações.

### O ícone na bandeja do sistema

Menu da bandeja

Clique com o botão direito (ou, em alguns sistemas, o esquerdo) no ícone da
bandeja para:
- **Abrir** — traz a janela principal de volta.
- **Sair** — encerra o app de verdade (os mapeamentos de botões/encoders
  param de funcionar até você reabrir, e os LEDs do pad ficam vermelho
  sólido).

### Onde suas configurações ficam salvas

Seus mapeamentos de botões, alvos de encoder e configurações de cor ficam
guardados em:

```
%APPDATA%\NeoCraft Macro Desk\config.json
```

Esse arquivo permanece entre atualizações e reinstalações do app. Apagá-lo
reseta tudo para o padrão na próxima vez que o app abrir.

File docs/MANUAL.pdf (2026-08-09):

## NeoCraft Macro Desk — User Manual

A custom macro pad: a 4×4 button grid plus 3 rotary encoders, paired with a Windows desktop app that decides what each button and encoder does.

### Part 1 — What it does

The hardware

16 buttons arranged in a 4×4 grid. 15 of them ( BTN0 – BTN14 ) run actions you assign. The 16th, 2FX , is not an action button — it's a layer switch (see below).
3 rotary encoders ( ENC1 – ENC3 ). Turning one adjusts a volume; clicking it in mutes/unmutes. Currently only ENC1 is wired up in the firmware — ENC2 and ENC3 are physically present but not active yet.
Addressable LEDs, one per key, showing an animated color pattern while everything's connected, or solid red if the app isn't running/connected — a built-in reminder to start the app.

The app

A small program that lives in your system tray. It talks to the pad over USB and lets you assign an action to every button, and a volume target to every encoder. Each button can do one of these:

Action type | What it does
Keyboard | Sends a key combo (e.g. ctrl+c ) to whatever app is focused
Macro | Same as Keyboard, but you record the combo by pressing it live instead of typing it
OBS Scene | Switches OBS Studio to a specific scene (requires OBS running with its WebSocket server on)
Sound | Plays an audio file (WAV, MP3, OGG, FLAC, AIFF) — with volume and trim controls
Empty | Does nothing (the button's default state)

Each encoder can control either your system's overall volume, or the volume of one specific application (even multi-window apps like a browser) — your choice, set per encoder.

The "2FX" second layer

Every button can hold two different actions — a normal one (Layer 1) and a second one (Layer 2) that only fires when you deliberately arm it:

1. Tap 2FX — the border flashes red, Layer 2 is now armed.
2. Tap any other button — it runs that button's Layer 2 action, then the pad automatically drops back to Layer 1.
3. If you don't press anything, Layer 2 auto-cancels after a timeout (10 seconds by default, adjustable up to 60s).
4. Tapping 2FX again while armed cancels it manually, with no action run.

This is how one 16-key pad gives you effectively 30 assignable actions.

Background operation

Closing the app window (the X button) doesn't quit it — it minimizes to the system tray and keeps running, so your button/encoder mappings stay active. Use the tray icon's Quit option to fully exit.

Language

The app is available in English and Português, switchable at any time from Settings (see Changing the app language). Defaults to Português. Note: the screenshots in this manual were captured before this feature existed, so a few labels shown (dialog titles, button text) are in whichever language they defaulted to at the time — the dialog layout and flow are identical, only the wording changes per language now.

### Part 2 — Installation

1. Download NeoCraft-Macro-Desk-Setup.exe .
2. Double-click it. No administrator prompt will appear — this installs just for your Windows account, not system-wide.
3. Optionally check "Create a desktop shortcut" in the wizard.
4. Click through to finish. The installer creates a Start Menu entry (NeoCraft Macro Desk) and an uninstaller.
5. Plug in the macro pad via USB.
6. Launch the app (Start Menu, or the desktop shortcut if you created one).

The app connects automatically — no setup dialog, no drivers to install separately (Windows' built-in USB-serial driver handles the Pro Micro). It finds the pad by its USB identity, not a fixed COM port number, so it connects correctly no matter which COM port Windows assigns it (which can change if you plug it into a different USB port).

If the LEDs stay solid red after launching the app: the app isn't seeing the pad at all — check the USB cable/connection, and confirm it shows up in Windows Device Manager under Ports (COM & LPT).

To uninstall: Start Menu → NeoCraft Macro Desk → "Uninstall NeoCraft Macro Desk," or Windows Settings → Apps. Your saved button/encoder configuration is kept (in case you reinstall later) — see Where your settings are saved if you want to remove it manually too.

### Part 3 — How to use each function

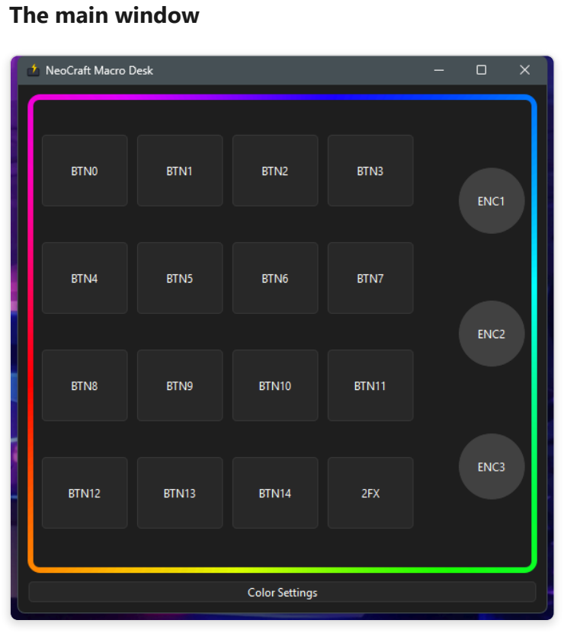
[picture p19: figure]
The main window

Note: this screenshot predates a small layout change — the single bottom button is now three side by side: Color Settings, Settings, and Help (see below).

A 4×4 grid of buttons plus the 3 encoders on the right. The animated border shows the pad's current LED pattern live. Click any button to configure it. Below the grid, three buttons: - Color Settings — change the LED pattern (see Changing the LED pattern). - Settings — 2FX timeout and app language (see Changing the app language). - Help — app version and links to this manual and the GitHub repo (see Help).

Assigning a keyboard shortcut or macro to a button

1. Click the button you want to configure (e.g. BTN0 ).
2. Choose the Layer (Layer 1 = normal, Layer 2 (2FX) = second function).
3. Set Action type to Keyboard or Macro.
4. Keyboard: type the combo directly, e.g. ctrl+c .
5. Macro: click into the field and press the actual key combo on your keyboard — it's captured live.
6. Click OK to save.

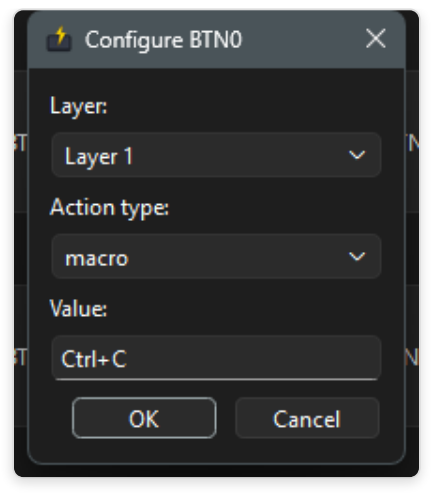
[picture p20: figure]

Assigning a sound to a button

1. Click the button, set Action type to Sound.
2. Click Browse... and pick an audio file (WAV, MP3, OGG, FLAC, or AIFF).
3. Adjust Volume with the slider (0–100%).
4. Drag the two handles under Trim to play only part of the clip — the label below shows the selected start/end time and the clip's total length.
5. Use ▶ Play preview / ■ Stop to check it sounds right before saving.
6. Click OK.

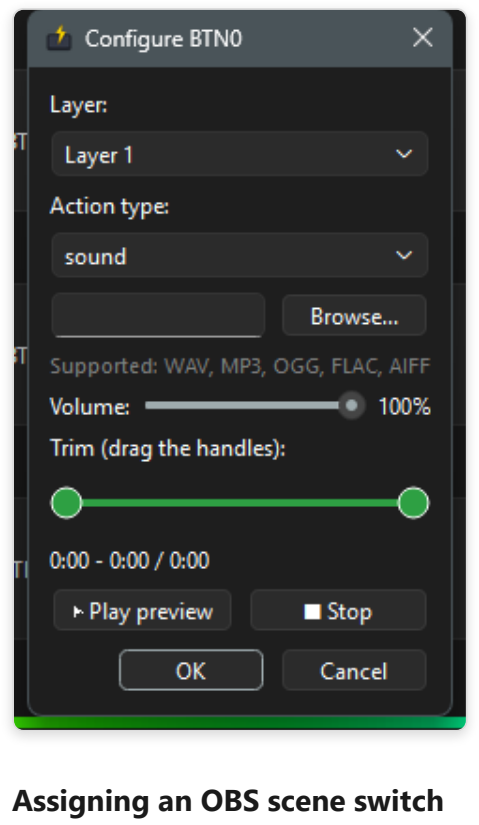
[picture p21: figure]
Assigning an OBS scene switch

1. Click the button, set Action type to OBS Scene.

2. Type the exact scene name as it appears in OBS.
3. Click OK.

This requires OBS Studio running with its WebSocket server enabled (OBS 28+ has this built in — Tools → WebSocket Server Settings).

Clearing a button

Set its Action type to Empty and click OK.

Using the 2FX second layer

Tap the 2FX key on the pad (bottom-right of the grid). The app border flashes red while armed. The next button you press runs its Layer 2 action instead of Layer 1, then the pad returns to normal automatically. Tap 2FX again before pressing anything else to cancel without running an action.

To change how long Layer 2 stays armed before auto-canceling, click the Settings button below the

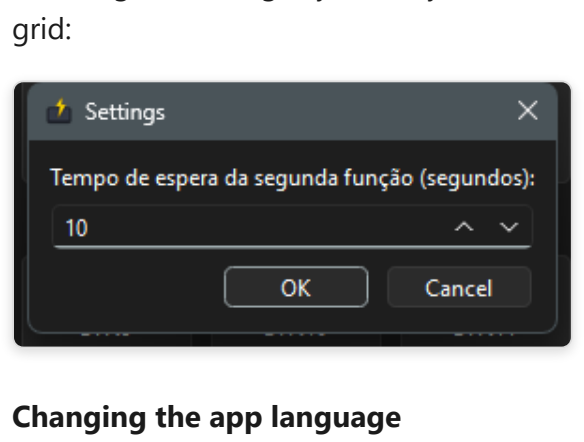
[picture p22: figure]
grid:; Changing the app language

Open the same Settings dialog and use the Language / Idioma dropdown at the bottom — pick English or Português and click OK. The change applies immediately: any dialog you open next (button config, encoder config, color settings) shows the new language right away, no restart needed. The Color Settings/Settings/Help buttons and the tray menu's Open/Quit labels update immediately too.

Help

Click the Help button below the grid for the app's version number and two links — one to this manual on GitHub, one to the project's GitHub repo. Both open in your default browser.

Configuring an encoder

1. Click an encoder ( ENC1 , ENC2 , or ENC3 ) in the app window.
2. Choose the mode:

3. System Volume (Volume Geral in Português) — controls your system's overall Windows volume.
4. Application (Aplicativo) — controls one specific application's volume independently (click Select... and pick its .exe ). This works correctly even for apps that run as many processes at once, like Chromium-based browsers.
5. Click OK.

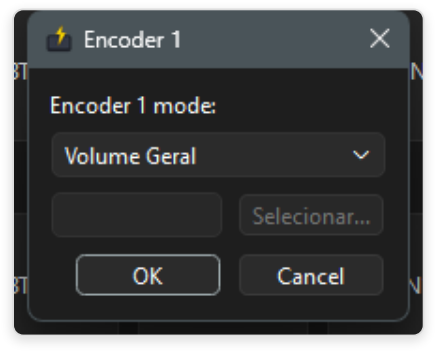
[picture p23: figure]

Once configured: turn the encoder to adjust volume up/down, click it (push down) to mute/unmute.

Changing the LED pattern

Click Color Settings at the bottom of the main window.

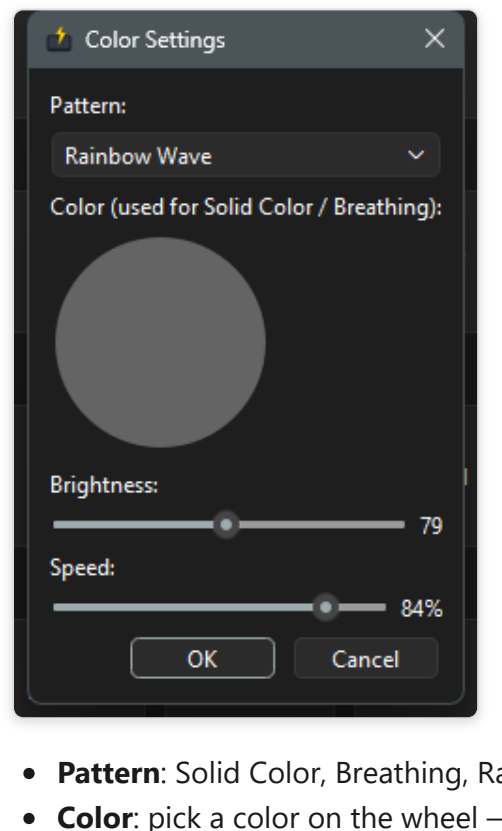
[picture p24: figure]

Pattern: Solid Color, Breathing, Rainbow Wave, or Color Cycle.
Color: pick a color on the wheel — only used by Solid Color and Breathing (grayed out otherwise, since Rainbow Wave and Color Cycle generate their own colors).
Brightness / Speed: sliders, applied immediately and saved with the rest of your settings.

The system tray icon

Right-click (or on some systems, left-click) the tray icon for: - Open — bring the main window back. -Quit — fully close the app (button/encoder mappings stop working until you reopen it, and the pad's LEDs go solid red).

Where your settings are saved

Your button mappings, encoder targets, and color settings are stored in:

%APPDATA%\NeoCraft Macro Desk\config.json

This file persists across app updates and reinstalls. Deleting it resets everything to defaults the next time the app starts.

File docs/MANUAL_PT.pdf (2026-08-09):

## NeoCraft Macro Desk — Manual do Usuário

Um macro pad personalizado: uma grade de 16 botões (4×4) mais 3 encoders rotativos, junto com um aplicativo de desktop para Windows que decide o que cada botão e encoder faz.

### Parte 1 — O que ele faz

O hardware

### 16 botões organizados em uma grade 4×4. 15 deles ( BTN0 – BTN14 ) executam ações que você

define. O 16º, 2FX , não é um botão de ação — é uma tecla de troca de camada (veja abaixo).
3 encoders rotativos ( ENC1 – ENC3 ). Girar ajusta um volume; clicar (apertar) muta/desmuta. No momento, apenas o ENC1 está ativo no firmware — ENC2 e ENC3 estão fisicamente presentes, mas ainda não funcionam.
LEDs endereçáveis, um por tecla, mostrando um padrão de cor animado enquanto tudo está conectado, ou vermelho sólido se o aplicativo não estiver rodando/conectado — um lembrete visual embutido para abrir o app.

O aplicativo

Um programinha que fica na bandeja do sistema (system tray). Ele conversa com o pad via USB e permite atribuir uma ação a cada botão, e um alvo de volume a cada encoder. Cada botão pode fazer uma destas ações:

Tipo de ação | O que faz
Teclado | Envia uma combinação de teclas (ex.: ctrl+c ) para o app que estiver em foco
Macro | Igual ao Teclado, mas você grava a combinação apertando-a de verdade, em vez de digitar
Cena OBS | Troca a cena do OBS Studio para uma cena específica (requer o OBS rodando com o servidor WebSocket ligado)
Som | Toca um arquivo de áudio (WAV, MP3, OGG, FLAC, AIFF) — com controles de volume e corte
Vazio | Não faz nada (estado padrão do botão)

Cada encoder pode controlar o volume geral do sistema, ou o volume de um aplicativo específico (mesmo apps com várias janelas, como um navegador) — você escolhe, por encoder.

A segunda camada "2FX"

Todo botão pode ter duas ações diferentes — uma normal (Camada 1) e uma segunda (Camada 2) que só dispara quando você arma deliberadamente:

1. Toque em 2FX — a borda do app pisca vermelho, a Camada 2 fica armada.
2. Toque em qualquer outro botão — ele executa a ação da Camada 2 daquele botão, e o pad volta automaticamente para a Camada 1.
3. Se você não apertar nada, a Camada 2 se desarma sozinha depois de um tempo (10 segundos por padrão, ajustável até 60s).
4. Tocar em 2FX de novo enquanto está armado cancela manualmente, sem executar nenhuma ação.

É assim que um pad de 16 teclas te dá, na prática, 30 ações configuráveis.

Funcionamento em segundo plano

Fechar a janela do app (o botão X) não encerra o programa — ele minimiza para a bandeja do sistema e continua rodando, então seus mapeamentos de botões/encoders continuam ativos. Use a opção Sair no menu da bandeja para encerrar de verdade.

Idioma

O aplicativo está disponível em Português e English, trocável a qualquer momento em Configurações (veja Trocando o idioma do aplicativo). O padrão é Português. Nota: as capturas de tela deste manual foram feitas antes desse recurso existir, então alguns rótulos mostrados (títulos de janela, texto de botão) estão no idioma que era padrão na época — o layout e o fluxo das janelas são idênticos, só o texto muda conforme o idioma agora.

### Parte 2 — Instalação

1. Baixe o NeoCraft-Macro-Desk-Setup.exe .
2. Dê duplo clique nele. Nenhuma solicitação de administrador vai aparecer — a instalação é só para a sua conta do Windows, não para o sistema todo.
3. Opcionalmente marque "Create a desktop shortcut" no assistente.
4. Avance até o fim. O instalador cria uma entrada no Menu Iniciar (NeoCraft Macro Desk) e um desinstalador.
5. Conecte o macro pad via USB.
6. Abra o aplicativo (Menu Iniciar, ou o atalho na área de trabalho, se você criou um).

O aplicativo conecta automaticamente — sem tela de configuração, sem drivers para instalar separadamente (o driver USB-serial embutido do Windows já cuida do Pro Micro). Ele encontra o pad pela identidade USB dele, não por um número fixo de porta COM, então conecta corretamente não importa em qual porta COM o Windows o coloque (o que pode mudar se você plugar em uma porta USB diferente).

Se os LEDs ficarem vermelho sólido depois de abrir o app: o aplicativo não está enxergando o pad de jeito nenhum — confira o cabo/conexão USB, e confirme que ele aparece no Gerenciador de Dispositivos do Windows, em Portas (COM & LPT).

Para desinstalar: Menu Iniciar → NeoCraft Macro Desk → "Uninstall NeoCraft Macro Desk", ou Configurações do Windows → Aplicativos. Sua configuração salva de botões/encoders é mantida (caso você reinstale depois) — veja Onde suas configurações ficam salvas se quiser removê-la manualmente também.

### Parte 3 — Como usar cada função

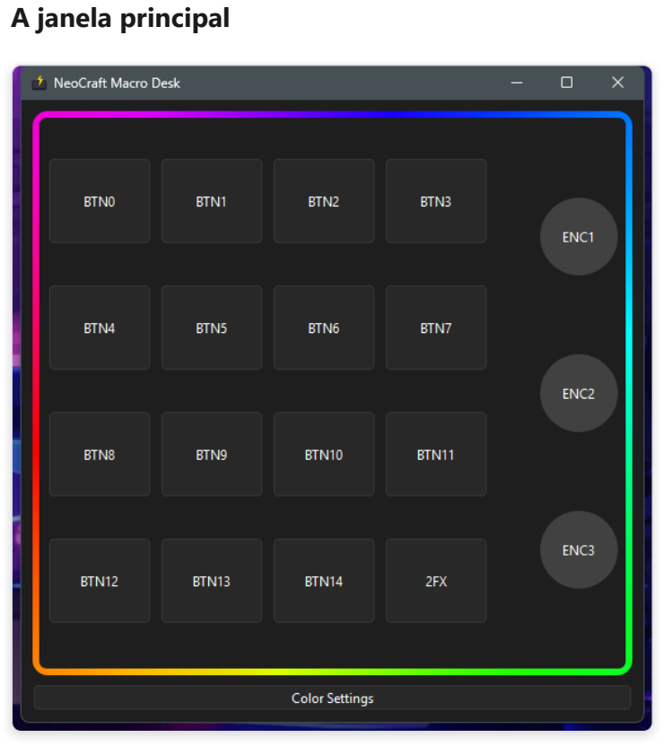
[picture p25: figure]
A janela principal

Nota: esta captura de tela é de antes de uma pequena mudança de layout — o único botão embaixo agora são três, lado a lado: Configurações de Cor, Configurações e Ajuda (veja abaixo).

Uma grade 4×4 de botões, mais os 3 encoders à direita. A borda animada mostra o padrão de LED atual do pad, ao vivo. Clique em qualquer botão para configurá-lo. Abaixo da grade, três botões: -Configurações de Cor — muda o padrão de LED (veja Mudando o padrão de LED). - Configurações — tempo da 2FX e idioma do app (veja Trocando o idioma do aplicativo). - Ajuda — versão do app e links para este manual e para o repositório no GitHub (veja Ajuda).

Atribuindo um atalho de teclado ou macro a um botão

1. Clique no botão que quer configurar (ex.: BTN0 ).
2. Escolha a Camada (Camada 1 = normal, Camada 2 (2FX) = segunda função).
3. Defina o Tipo de ação como Teclado ou Macro.
4. Teclado: digite a combinação diretamente, ex.: ctrl+c .
5. Macro: clique no campo e aperte a combinação de verdade no seu teclado — ela é capturada ao vivo.
6. Clique em OK para salvar.


Atribuindo um som a um botão

1. Clique no botão, defina o Tipo de ação como Som.
2. Clique em Procurar... e escolha um arquivo de áudio (WAV, MP3, OGG, FLAC ou AIFF).
3. Ajuste o Volume com o controle deslizante (0–100%).
4. Arraste as duas alças em Corte para tocar só parte do clipe — o texto abaixo mostra o início/fim selecionado e a duração total.
5. Use ▶ Testar som / ■ Parar para conferir se está do jeito certo antes de salvar.
6. Clique em OK.

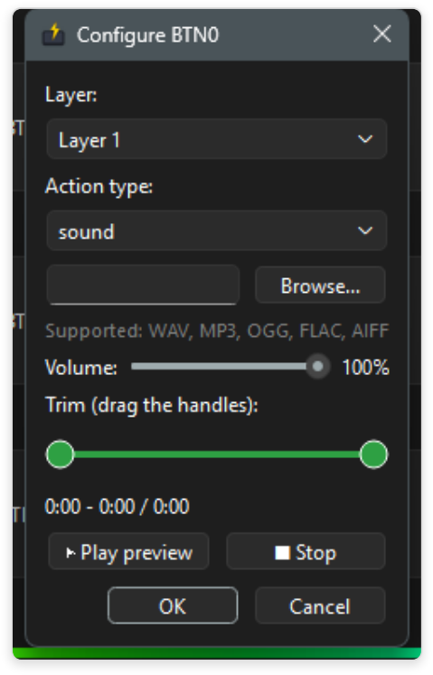
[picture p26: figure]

Atribuindo uma troca de cena do OBS

1. Clique no botão, defina o Tipo de ação como Cena OBS.

2. Digite o nome exato da cena como aparece no OBS.
3. Clique em OK.

Isso requer o OBS Studio rodando com o servidor WebSocket habilitado (o OBS 28+ já vem com isso — Tools → WebSocket Server Settings).

Limpando um botão

Defina o Tipo de ação como Vazio e clique em OK.

Usando a segunda camada 2FX

Toque na tecla 2FX do pad (canto inferior direito da grade). A borda do app pisca vermelho enquanto está armada. O próximo botão que você apertar executa sua ação da Camada 2 em vez da Camada 1, e o pad volta ao normal automaticamente. Toque em 2FX de novo antes de apertar outra coisa para cancelar sem executar nenhuma ação.

Para mudar quanto tempo a Camada 2 fica armada antes de desarmar sozinha, clique no botão

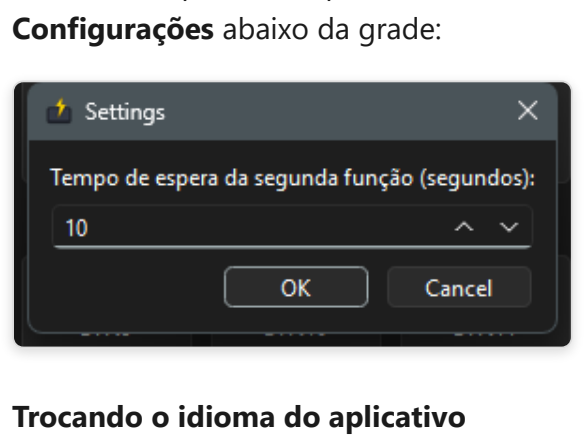
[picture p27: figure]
Configurações abaixo da grade:; Trocando o idioma do aplicativo

Abra a mesma janela de Configurações e use o menu Idioma / Language na parte de baixo — escolha Português ou English e clique em OK. A mudança é aplicada na hora: qualquer janela que você abrir em seguida (configurar botão, configurar encoder, configurações de cor) já aparece no novo idioma, sem precisar reiniciar. Os botões Configurações de Cor/Configurações/Ajuda e os textos Abrir/ Sair do menu da bandeja também atualizam na hora.

Ajuda

Clique no botão Ajuda abaixo da grade para ver o número da versão do app e dois links — um para este manual no GitHub, outro para o repositório do projeto. Os dois abrem no seu navegador padrão.

Configurando um encoder

1. Clique em um encoder ( ENC1 , ENC2 ou ENC3 ) na janela do app.

2. Escolha o modo:
3. Volume Geral (System Volume em inglês) — controla o volume geral do Windows.
4. Aplicativo (Application) — controla o volume de um app específico, independentemente (clique em Selecionar... e escolha o .exe ). Funciona corretamente até com apps que rodam como vários processos ao mesmo tempo, como navegadores baseados em Chromium.
5. Clique em OK.


Depois de configurado: gire o encoder para ajustar o volume, clique nele (aperte para baixo) para mutar/desmutar.

Mudando o padrão de LED

Clique em Configurações de Cor na parte de baixo da janela principal.

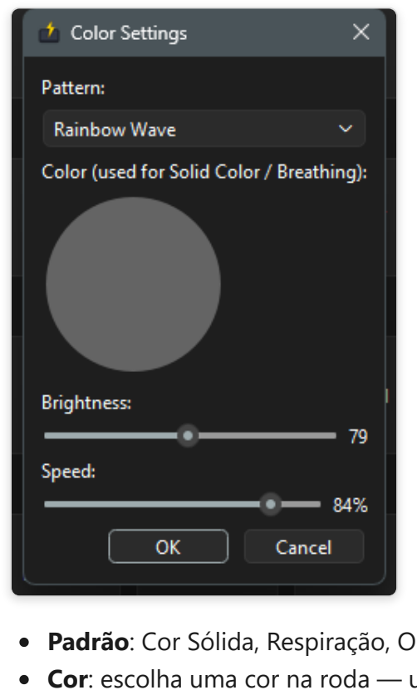
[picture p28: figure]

Padrão: Cor Sólida, Respiração, Onda Arco-íris ou Ciclo de Cor.
Cor: escolha uma cor na roda — usada apenas por Cor Sólida e Respiração (fica desabilitada nos outros modos, já que Onda Arco-íris e Ciclo de Cor geram suas próprias cores).

Brilho / Velocidade: controles deslizantes, aplicados na hora e salvos junto com o resto das suas configurações.

O ícone na bandeja do sistema

Clique com o botão direito (ou, em alguns sistemas, o esquerdo) no ícone da bandeja para: - Abrir — traz a janela principal de volta. - Sair — encerra o app de verdade (os mapeamentos de botões/encoders param de funcionar até você reabrir, e os LEDs do pad ficam vermelho sólido).

Onde suas configurações ficam salvas

Seus mapeamentos de botões, alvos de encoder e configurações de cor ficam guardados em:

%APPDATA%\NeoCraft Macro Desk\config.json

Esse arquivo permanece entre atualizações e reinstalações do app. Apagá-lo reseta tudo para o padrão na próxima vez que o app abrir.

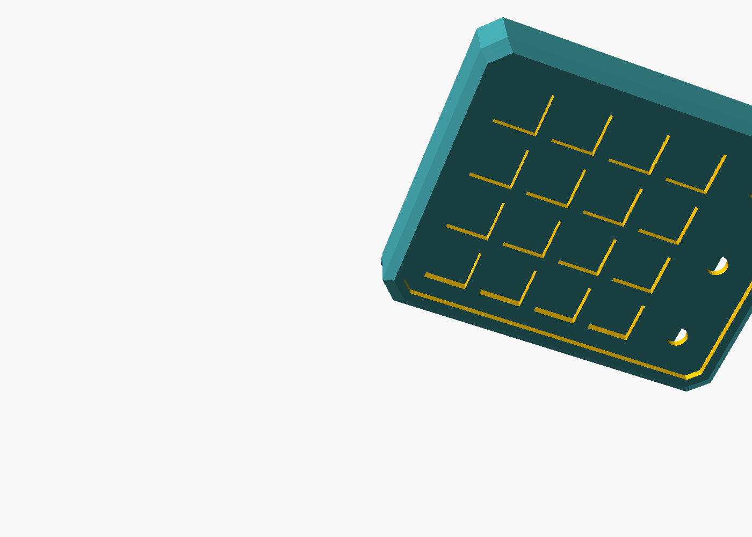
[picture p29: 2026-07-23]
case/renders/case_v4_assembly_below2.png

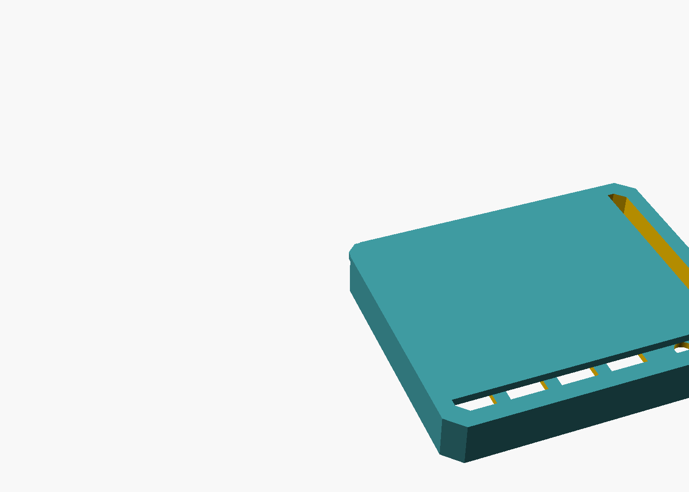
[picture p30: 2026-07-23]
case/renders/case_v4_assembly_below.png

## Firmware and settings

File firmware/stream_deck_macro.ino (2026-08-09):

#include <Adafruit_NeoPixel.h>

// Identity string for the "ID?" handshake — app.py matches on this exact
// string (see DEVICE_ID_RESPONSE in app.py) to confirm it's actually
// talking to THIS project's firmware, not just any board that shares the
// same USB VID:PID (which only identifies the Pro Micro model, not the
// specific device/project running on it).
#define DEVICE_ID "ID:NEOCRAFT_MACRO_DESK:v1"

// ---- Button matrix ----
const int rowPins[4] = {3, 4, 5, 6};
const int colPins[4] = {7, 8, 9, 10};
bool btnState[16] = {false};
unsigned long lastChangeTime[16] = {0};
const unsigned long DEBOUNCE_MS = 30;

// ---- Encoder 1 ----
const int ENC1_CLK = 0;   // D0 / RXI
const int ENC1_DT  = A0;
const int ENC1_SW  = A1;
volatile int enc1Delta = 0;
volatile int enc1LastCLK;
volatile unsigned long enc1LastTime = 0;
const unsigned long ENC_DEBOUNCE_US = 5000;
const unsigned long SW_DEBOUNCE_MS = 30;

// ---- Host connection watchdog ----
// app.py sends "PING" once a second; if 3s pass with no line at all from
// the host, we assume it's gone (closed, crashed, or unplugged) and show
// solid red until it comes back.
unsigned long lastHostContact = 0;
const unsigned long HOST_TIMEOUT_MS = 3000;
bool hostConnected = true;

// ---- LEDs ----
#define LED_PIN 16
#define NUM_LEDS 9   // set to however many you have wired right now

Adafruit_NeoPixel strip(NUM_LEDS, LED_PIN, NEO_GRB + NEO_KHZ800);

enum LedMode { MODE_SOLID, MODE_BREATHE, MODE_RAINBOWWAVE, MODE_COLORCYCLE };
LedMode currentMode = MODE_RAINBOWWAVE;
uint8_t breatheR = 255, breatheG = 0, breatheB = 0;
uint16_t animSpeedMs = 20;
unsigned long lastAnimStep = 0;
uint32_t rainbowHue = 0;
int breathePhase = 0;
bool breatheIncreasing = true;

void enc1ISR() {
  unsigned long now = micros();
  if (now - enc1LastTime < ENC_DEBOUNCE_US) return;

  int clk = digitalRead(ENC1_CLK);
  if (clk != enc1LastCLK) {
    if (clk == LOW) {
      if (digitalRead(ENC1_DT) != clk) {
        enc1Delta--;
      } else {
        enc1Delta++;
      }
    }
    enc1LastCLK = clk;
    enc1LastTime = now;
  }
}

void setup() {
  Serial.begin(9600);
  lastHostContact = millis();

  for (int i = 0; i < 4; i++) {
    pinMode(rowPins[i], OUTPUT);
    digitalWrite(rowPins[i], HIGH);
  }
  for (int i = 0; i < 4; i++) {
    pinMode(colPins[i], INPUT_PULLUP);
  }

  pinMode(ENC1_CLK, INPUT_PULLUP);
  pinMode(ENC1_DT, INPUT_PULLUP);
  pinMode(ENC1_SW, INPUT_PULLUP);
  enc1LastCLK = digitalRead(ENC1_CLK);
  attachInterrupt(digitalPinToInterrupt(ENC1_CLK), enc1ISR, CHANGE);

  strip.begin();
  strip.setBrightness(50);
  strip.show();
}

void loop() {
  scanMatrix();
  handleEncoder();
  handleSerialCommand();
  checkHostConnection();
  updateLeds();
}

void checkHostConnection() {
  bool wasConnected = hostConnected;
  hostConnected = (millis() - lastHostContact) < HOST_TIMEOUT_MS;
  if (hostConnected == wasConnected) return;

  if (!hostConnected) {
    for (int i = 0; i < NUM_LEDS; i++) {
      strip.setPixelColor(i, strip.Color(255, 0, 0));
    }
    strip.show();
  }
  // Reconnecting doesn't need to do anything here — app.py re-sends the
  // real LED state right after opening the port (see on_serial_connected),
  // and updateLeds() below resumes its normal animation immediately since
  // it no longer sees currentMode forced to anything.
}

void scanMatrix() {
  for (int r = 0; r < 4; r++) {
    digitalWrite(rowPins[r], LOW);
    for (int c = 0; c < 4; c++) {
      int idx = r * 4 + c;
      bool pressed = (digitalRead(colPins[c]) == LOW);
      if (pressed != btnState[idx] && (millis() - lastChangeTime[idx]) > DEBOUNCE_MS) {
        btnState[idx] = pressed;
        lastChangeTime[idx] = millis();
        Serial.print("BTN:");
        Serial.print(idx);
        Serial.println(pressed ? ":DOWN" : ":UP");
      }
    }
    digitalWrite(rowPins[r], HIGH);
  }
}

void handleEncoder() {
  noInterrupts();
  int delta = enc1Delta;
  enc1Delta = 0;
  interrupts();

  if (delta > 0) {
    Serial.println("ENC:1:CW");
  } else if (delta < 0) {
    Serial.println("ENC:1:CCW");
  }

  static bool lastSW = false;
  static unsigned long lastSWChangeTime = 0;
  bool sw = (digitalRead(ENC1_SW) == LOW);
  if (sw != lastSW && (millis() - lastSWChangeTime) > SW_DEBOUNCE_MS) {
    lastSW = sw;
    lastSWChangeTime = millis();
    if (sw) {
      Serial.println("ENC:1:PUSH");
    }
  }
}

void handleSerialCommand() {
  if (Serial.available() == 0) return;
  String cmd = Serial.readStringUntil('\n');
  cmd.trim();
  lastHostContact = millis();

  if (cmd == "ID?") {
    // Identity handshake — lets the host tell this board apart from any
    // other Pro Micro that happens to be plugged in at the same time
    // (same USB VID:PID, since that only identifies the board MODEL, not
    // this specific device/project). See DEVICE_ID above.
    Serial.println(DEVICE_ID);

  } else if (cmd.startsWith("LED:MODE:SOLID:")) {
    int r, g, b;
    sscanf(cmd.c_str() + 15, "%d,%d,%d", &r, &g, &b);
    for (int i = 0; i < NUM_LEDS; i++) {
      strip.setPixelColor(i, strip.Color(r, g, b));
    }
    strip.show();
    currentMode = MODE_SOLID;

  } else if (cmd.startsWith("LED:MODE:BREATHE:")) {
    int r, g, b;
    sscanf(cmd.c_str() + 18, "%d,%d,%d", &r, &g, &b);
    breatheR = r; breatheG = g; breatheB = b;
    breathePhase = 0;
    breatheIncreasing = true;
    currentMode = MODE_BREATHE;

  } else if (cmd.startsWith("LED:MODE:RAINBOWWAVE")) {
    currentMode = MODE_RAINBOWWAVE;

  } else if (cmd.startsWith("LED:MODE:COLORCYCLE")) {
    currentMode = MODE_COLORCYCLE;

  } else if (cmd.startsWith("LED:BRIGHTNESS:")) {
    int val = cmd.substring(15).toInt();
    strip.setBrightness(val);

  } else if (cmd.startsWith("LED:SPEED:")) {
    int val = cmd.substring(10).toInt();
    animSpeedMs = val;
  }
}

void updateLeds() {
  if (!hostConnected) return;
  if (currentMode == MODE_SOLID) return;

  unsigned long now = millis();
  if (now - lastAnimStep < animSpeedMs) return;
  lastAnimStep = now;

  if (currentMode == MODE_RAINBOWWAVE) {
    for (int i = 0; i < NUM_LEDS; i++) {
      uint32_t pixelHue = rainbowHue + (i * 65536L / NUM_LEDS);
      strip.setPixelColor(i, strip.gamma32(strip.ColorHSV(pixelHue)));
    }
    strip.show();
    rainbowHue += 256;

  } else if (currentMode == MODE_COLORCYCLE) {
    uint32_t color = strip.gamma32(strip.ColorHSV(rainbowHue));
    for (int i = 0; i < NUM_LEDS; i++) {
      strip.setPixelColor(i, color);
    }
    strip.show();
    rainbowHue += 256;

  } else if (currentMode == MODE_BREATHE) {
    if (breatheIncreasing) {
      breathePhase += 5;
      if (breathePhase >= 250) breatheIncreasing = false;
    } else {
      breathePhase -= 5;
      if (breathePhase <= 5) breatheIncreasing = true;
    }
    for (int i = 0; i < NUM_LEDS; i++) {
      strip.setPixelColor(i, strip.Color(
        (breatheR * breathePhase) / 255,
        (breatheG * breathePhase) / 255,
        (breatheB * breathePhase) / 255
      ));
    }
    strip.show();
  }
}

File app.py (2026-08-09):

import os
import sys
import time
import json
import math
import colorsys
import serial
import serial.tools.list_ports
import sounddevice as sd
import soundfile as sf
import pyautogui
import obsws_python as obs
from pycaw.pycaw import AudioUtilities
from PySide6.QtCore import QTimer, Qt, Signal, QPointF, QRectF
from PySide6.QtGui import (
    QPainter, QColor, QImage, QPen, QIcon, QAction, QKeySequence,
    QPainterPath, QConicalGradient, QBrush,
)
from PySide6.QtWidgets import (
    QApplication, QMainWindow, QWidget, QGridLayout, QVBoxLayout, QHBoxLayout, QPushButton,
    QDialog, QComboBox, QLineEdit, QDialogButtonBox, QLabel, QSpinBox,
    QKeySequenceEdit, QFileDialog, QSlider, QSystemTrayIcon, QMenu
)

APP_NAME = "NeoCraft Macro Desk"
# Keep in sync with MyAppVersion in installer/setup.iss — not read from
# there automatically, this is the one place app.py itself knows its version.
APP_VERSION = "3.0.0"
REPO_URL = "https://github.com/NeoCraftStudio/stream-deck-macro"
MANUAL_URLS = {
    "en": f"{REPO_URL}/blob/master/docs/MANUAL.md",
    "pt": f"{REPO_URL}/blob/master/docs/MANUAL_PT.md",
}


def resource_base_dir():
    # When packaged by PyInstaller (--onefile), sys.executable is the .exe
    # itself and relative paths must resolve next to IT, not to the
    # temporary folder PyInstaller unpacks into at runtime (that folder is
    # wiped after each run, so config.json would never actually persist).
    if getattr(sys, "frozen", False):
        return os.path.dirname(sys.executable)
    return os.path.dirname(os.path.abspath(__file__))


def bundled_resource_dir():
    # Read-only assets bundled into the exe (via --add-data) land in the
    # temp extraction folder at runtime, NOT next to the exe like
    # config.json — that's sys._MEIPASS for a --onefile build.
    if getattr(sys, "frozen", False):
        return getattr(sys, "_MEIPASS", os.path.dirname(sys.executable))
    return os.path.dirname(os.path.abspath(__file__))


def user_data_dir():
    # Where per-user, writable data (config.json) lives — independent of
    # where the app binary itself is installed. An installed app's own
    # folder isn't a safe place to write: Program Files needs admin, and
    # even a per-user install shouldn't assume its own directory stays
    # writable. %APPDATA% is the standard Windows location for this.
    if getattr(sys, "frozen", False):
        base = os.environ.get("APPDATA", BASE_DIR)
        path = os.path.join(base, APP_NAME)
        os.makedirs(path, exist_ok=True)
        return path
    return os.path.dirname(os.path.abspath(__file__))


BASE_DIR = resource_base_dir()
ICON_PATH = os.path.join(bundled_resource_dir(), "assets", "icon.ico")
CONFIG_PATH = os.path.join(user_data_dir(), "config.json")
# SparkFun Pro Micro's USB VID:PID — used to find the pad's COM port
# automatically instead of assuming a fixed port number, since Windows
# assigns COM numbers per USB physical port, not per device: the same
# board shows up as a different COM# depending which port/hub it's
# plugged into.
PAD_VID = 0x1B4F
PAD_PID = 0x9206
BAUD = 9600
VOLUME_STEP = 0.05

DEFAULT_CONFIG = {
    "settings": {
        "2fx_timeout_seconds": 10,
        "led_brightness": 50,
        "led_speed_percent": 50,
        "led_pattern": "rainbow_wave",
        "led_color": [255, 0, 0],
        "language": "pt",
    },
    "buttons": {},
    "encoders": {},
}

if not os.path.exists(CONFIG_PATH):
    with open(CONFIG_PATH, "w") as f:
        json.dump(DEFAULT_CONFIG, f, indent=2)

with open(CONFIG_PATH, "r") as f:
    config = json.load(f)

config["settings"].setdefault("led_brightness", 50)
config["settings"].setdefault("led_speed_percent", 50)
config["settings"].setdefault("led_pattern", "rainbow_wave")
config["settings"].setdefault("led_color", [255, 0, 0])
config["settings"].setdefault("language", "pt")
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

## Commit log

2026-07-19 changes before finding the Arduino Pro Micro voltage, its 5V
2026-07-19 atualization after Arduino Pro Micro first test with computer connection
2026-07-19 after Arduino protoboard mounting and testing
2026-07-19 test of 2 layers configuration of the button matrix
2026-07-19 after sound test and driver installation
2026-07-23 primeiras iterações do modelo 3D
    [Case_Bottom.stl, Case_Top.stl, Knob.stl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]
2026-08-04 Split top into crest/mount/deck, add pins, Arduino mount, deck reinforcement
    - Split monolithic case_top_tilted() into 3 separate prints: crest_piece()
    (bevel ring), top_mount_piece() (wall), deck_piece() (switch/encoder plate)
    - Pins split into their own piece (pins_piece()), bent to match the crest's
    slope where they seat; both crest and mount get straight holes
    - Deck mounts via 6 square tabs into matching notches in the mount wall,
    with a floor so the deck actually seats instead of sliding freely
    - Added Arduino Pro Micro pocket (bottom tray, back-aligned) + matching
    USB-C cable cutout through both the mount's and tray's back walls
    - Added waffle-grid reinforcement ribs to the de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
    [case_params.scad, case_v4_bottom.scad, case_v4_top.scad]
2026-08-04 Add STL exports for crest/mount/deck/pins/bottom pieces
    Reference exports from case_v4_top.scad and case_v4_bottom.scad, matching
    the geometry committed and validated in 49d9362.
    [case_bottom.stl, case_crest.stl, case_deck.stl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]
2026-08-09 Add disconnect watchdog, perf fixes, installer, i18n, and user manual
    - Firmware: heartbeat-based disconnect indicator (solid red LEDs when the
    app isn't connected), synced firmware/stream_deck_macro.ino with the
    version actually running on the board (was badly out of date).
    - App: fixed ~14% idle CPU usage (border animation redrew as 150 line
    segments/frame; now a single QConicalGradient-stroked path, paused
    entirely while minimized to tray).
    - Custom keycap+lightning icon (assets/, tools/make_icon.py) wired into
    the window, tray, and exe.
    - Packaging switched from PyInstaller --onefile to --onedir + a real
    per-user Inno Setup installer (installer/setup.iss, no admin/UAC
    neede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
    [app.py, stream_deck_macro.ino]
2026-08-09 Auto-detect pad by USB identity, then verify with a handshake (V3.0)
    - v2.2.0 step: stop hardcoding COM5, match the board's USB VID:PID
    (1B4F:9206) instead so the app finds the pad on whatever COM port
    Windows assigns it, including after unplug/replug into a different port.
    - v3.0.0 step: VID:PID alone only identifies the Pro Micro *model*, not a
    specific device - if a second board of the same kind is plugged in,
    that's not enough to tell them apart. Firmware now answers an identity
    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
